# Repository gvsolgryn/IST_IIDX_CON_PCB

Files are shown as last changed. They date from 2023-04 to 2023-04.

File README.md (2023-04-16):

# IST_IIDX_CON_PCB
ist 몰에서 만든 iidx 컨트롤러 PCB 딜레이가 너무 심해서 우리 기합찬 육군(만기전역)들이 설계하기로 하였다

## 기합찬 준비운동

1. 일단 KiCAD를 받는다
2. `git` 을 다운로드 받는다
3. `git clone https://github.com/gvsolgryn/IST_IIDX_CON_PCB.git` 을 하여 우리 기합찬 PCB 프로젝트를 다운로드 받는다
4. KiCAD를 실행 시킨 뒤 프로젝트를 연다
5. 불만이 있으면 KiCAD를 이용해서 PCB 다 수정해서 머지? 요청 하면 우리 기합찬 육군들이 업데이트를 해주도록 하겠다

## 악! PCB Gerber을 이용하여 PCB를 출력하고싶어 해병님!!
1. https://jlcpcb.com/ 에 방문한다
2. gerber.zip 을 Add Gerber File 에 드래그 엔 드롭 한다
3. 결제한다!

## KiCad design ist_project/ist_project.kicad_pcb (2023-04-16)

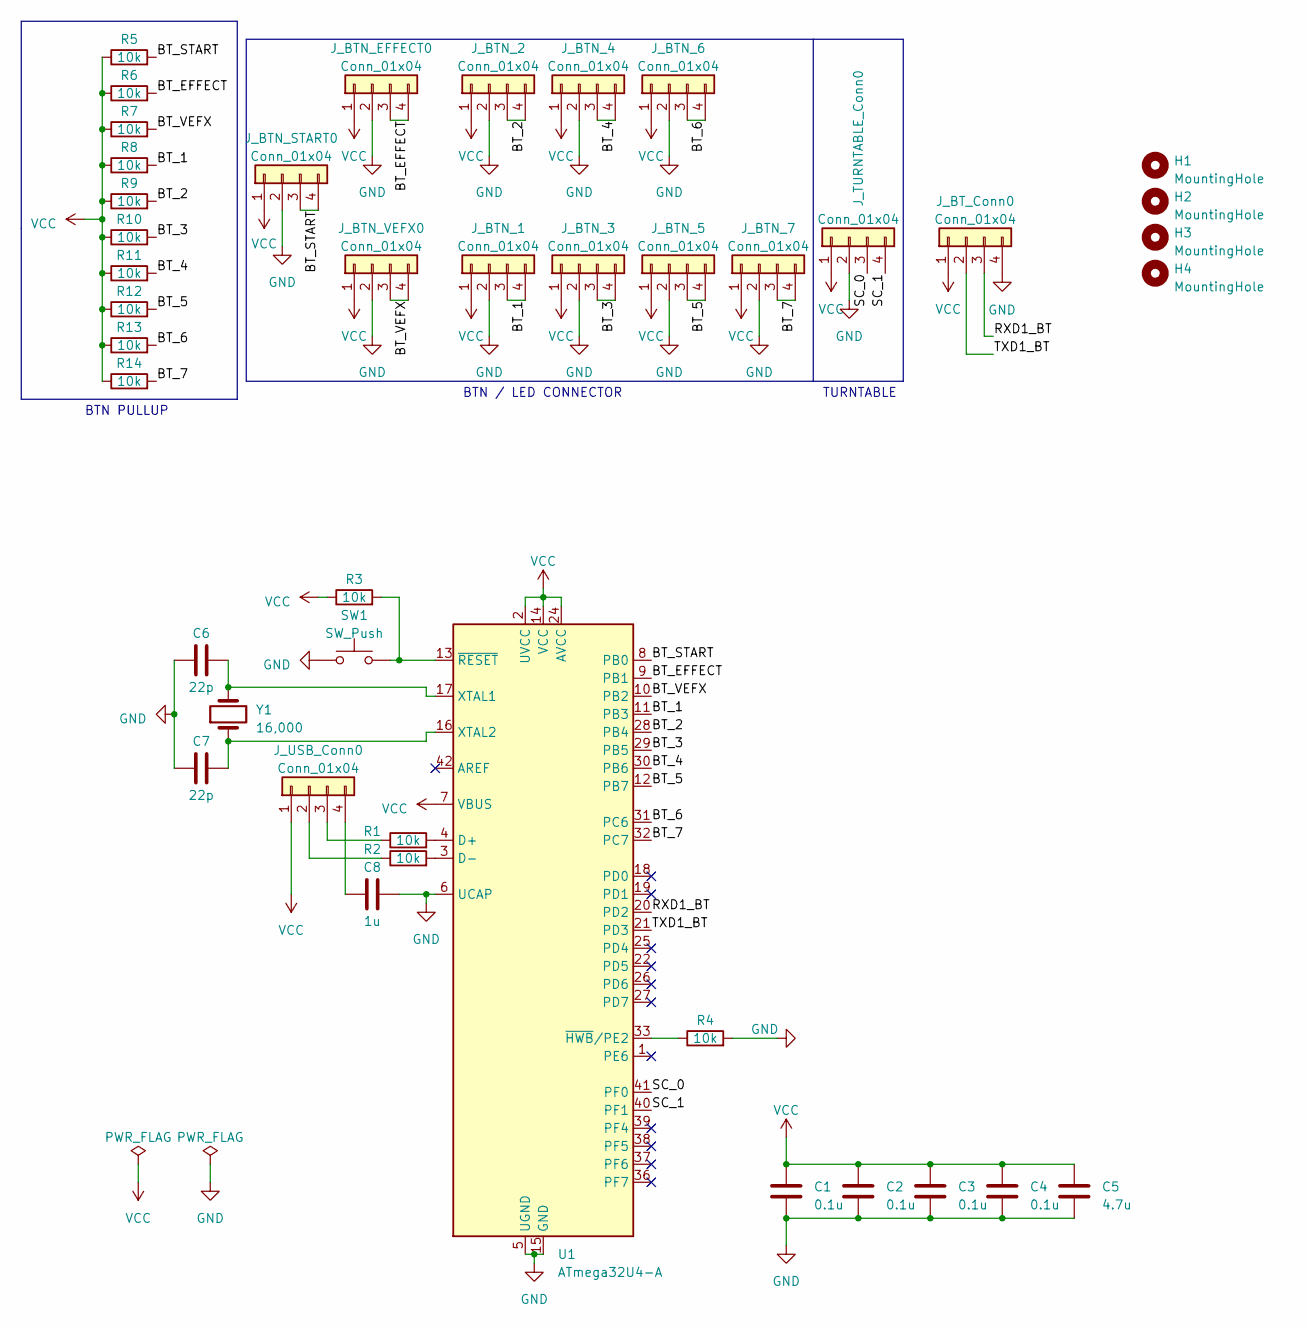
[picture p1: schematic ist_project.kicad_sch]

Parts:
C1, C2, C3, C4: 0.1u; C_0805_2012Metric_Pad1.18x1.45mm_HandSolder
C5: 4.7u; C_0805_2012Metric_Pad1.18x1.45mm_HandSolder
C6, C7: 22p; C_0805_2012Metric_Pad1.18x1.45mm_HandSolder
C8: 1u; C_0805_2012Metric_Pad1.18x1.45mm_HandSolder
H1, H2, H3, H4: MountingHole; MountingHole_3.2mm_M3_ISO7380_Pad_TopOnly
J_BTN_1, J_BTN_2, J_BTN_3, J_BTN_4, J_BTN_5, J_BTN_6, J_BTN_7: Conn_01x04; Molex_SPOX_5267-04A_1x04_P2.50mm_Vertical
J_BTN_EFFECT0: Conn_01x04; Molex_SPOX_5267-04A_1x04_P2.50mm_Vertical
J_BTN_START0: Conn_01x04; Molex_SPOX_5267-04A_1x04_P2.50mm_Vertical
J_BTN_VEFX0: Conn_01x04; Molex_SPOX_5267-04A_1x04_P2.50mm_Vertical
J_BT_Conn0: Conn_01x04; Molex_SPOX_5267-04A_1x04_P2.50mm_Vertical
J_TURNTABLE_Conn0: Conn_01x04; Molex_SPOX_5267-04A_1x04_P2.50mm_Vertical
J_USB_Conn0: Conn_01x04; Molex_SPOX_5267-04A_1x04_P2.50mm_Vertical
R1, R2, R3, R4, R5, R6, R7, R8, R9, R10, R11, R12, R13, R14: 10k; R_0805_2012Metric_Pad1.20x1.40mm_HandSolder
SW1: SW_Push; SW_Push_1P1T_NO_6x6mm_H9.5mm
U1: ATmega32U4-A; TQFP-44_10x10mm_P0.8mm
Y1: 16,000; Crystal_SMD_HC49-SD_HandSoldering

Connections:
/BT_1: J_BTN_1.3, J_BTN_1.4, R8.2, U1.11 (PB3)
/BT_2: J_BTN_2.3, J_BTN_2.4, R9.2, U1.28 (PB4)
/BT_3: J_BTN_3.3, J_BTN_3.4, R10.2, U1.29 (PB5)
/BT_4: J_BTN_4.3, J_BTN_4.4, R11.2, U1.30 (PB6)
/BT_5: J_BTN_5.3, J_BTN_5.4, R12.2, U1.12 (PB7)
/BT_6: J_BTN_6.3, J_BTN_6.4, R13.2, U1.31 (PC6)
/BT_7: J_BTN_7.3, J_BTN_7.4, R14.2, U1.32 (PC7)
/BT_EFFECT: J_BTN_EFFECT0.3, J_BTN_EFFECT0.4, R6.2, U1.9 (PB1)
/BT_START: J_BTN_START0.3, J_BTN_START0.4, R5.2, U1.8 (PB0)
/BT_VEFX: J_BTN_VEFX0.3, J_BTN_VEFX0.4, R7.2, U1.10 (PB2)
/RXD1_BT: J_BT_Conn0.3, U1.20 (PD2)
/SC_0: J_TURNTABLE_Conn0.3, U1.41 (PF0)
/SC_1: J_TURNTABLE_Conn0.4, U1.40 (PF1)
/TXD1_BT: J_BT_Conn0.2, U1.21 (PD3)
GND: C1.2, C2.2, C3.2, C4.2, C5.2, C6.1, C7.2, C8.2, J_BTN_1.2, J_BTN_2.2, J_BTN_3.2, J_BTN_4.2, J_BTN_5.2, J_BTN_6.2, J_BTN_7.2, J_BTN_EFFECT0.2, J_BTN_START0.2, J_BTN_VEFX0.2, J_BT_Conn0.4, J_TURNTABLE_Conn0.2, R4.2, SW1.1, U1.5 (UGND), U1.6 (UCAP), U1.15 (GND), U1.23 (GND), U1.35 (GND), U1.43 (GND)
unnamed: J_USB_Conn0.2, R2.1
unnamed: J_USB_Conn0.3, R1.1
unnamed: C8.1, J_USB_Conn0.4
unnamed: R1.2, U1.4 (D+)
unnamed: R2.2, U1.3 (D-)
unnamed: C6.2, U1.17 (XTAL1), Y1.2
unnamed: C7.1, U1.16 (XTAL2), Y1.1
unnamed: R4.1, U1.33 (~HWB/PE2)
unnamed: R3.2, SW1.2, U1.13 (~RESET)
VCC: C1.1, C2.1, C3.1, C4.1, C5.1, J_BTN_1.1, J_BTN_2.1, J_BTN_3.1, J_BTN_4.1, J_BTN_5.1, J_BTN_6.1, J_BTN_7.1, J_BTN_EFFECT0.1, J_BTN_START0.1, J_BTN_VEFX0.1, J_BT_Conn0.1, J_TURNTABLE_Conn0.1, J_USB_Conn0.1, R3.1, R5.1, R6.1, R7.1, R8.1, R9.1, R10.1, R11.1, R12.1, R13.1, R14.1, U1.2 (UVCC), U1.7 (VBUS), U1.14 (VCC), U1.24 (AVCC), U1.34 (VCC), U1.44 (AVCC)

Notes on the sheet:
TURNTABLE
BTN / LED CONNECTOR
BTN PULLUP

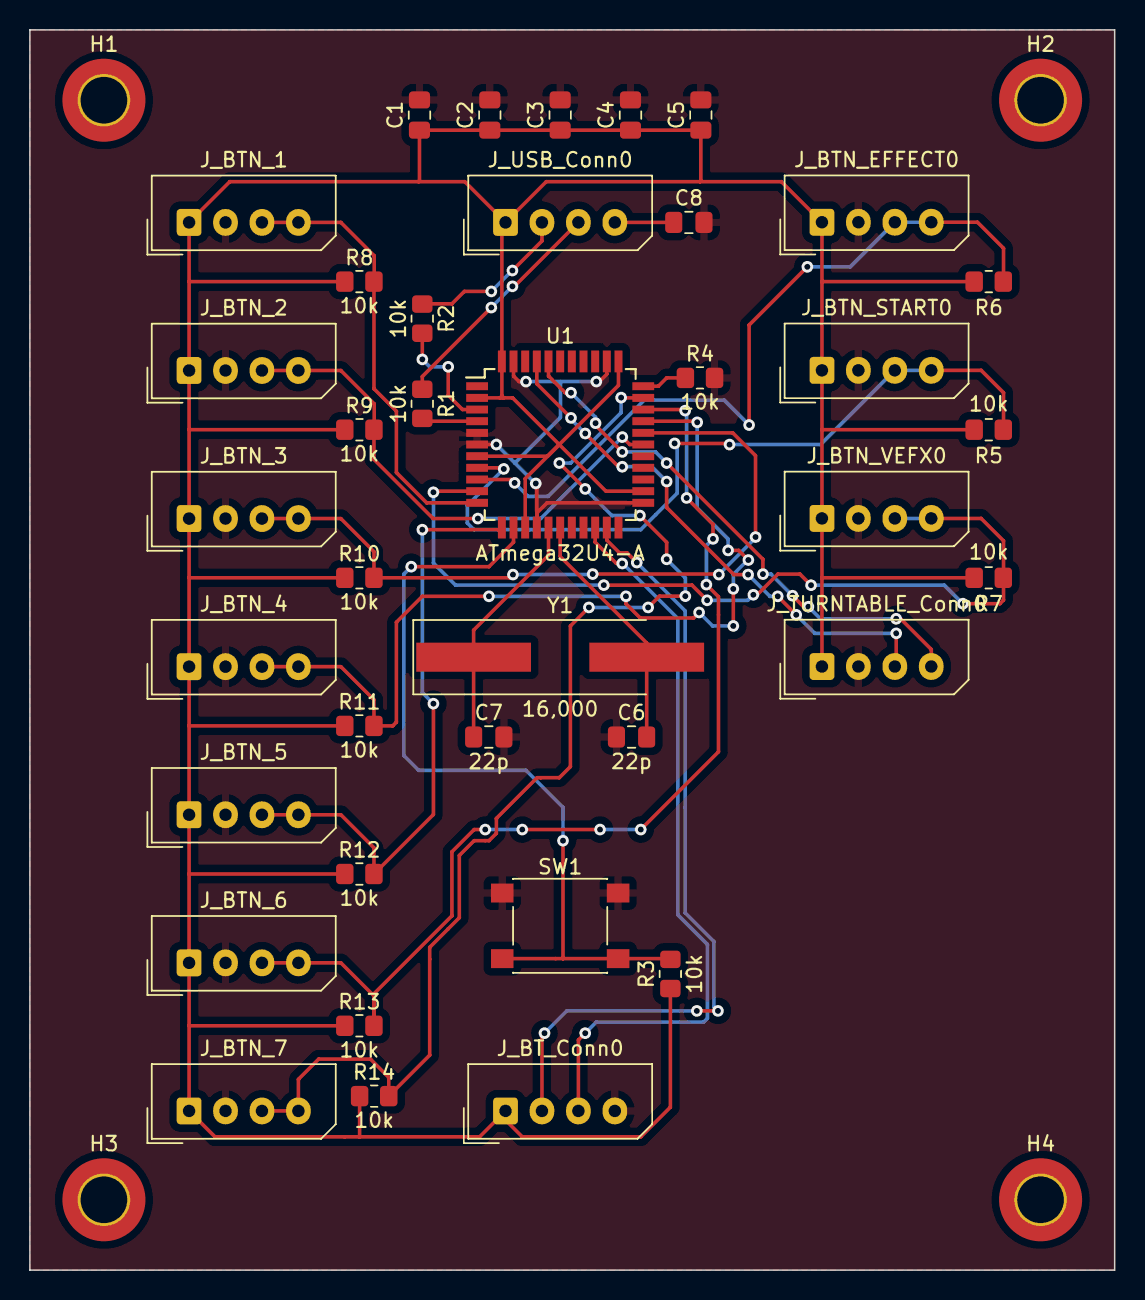
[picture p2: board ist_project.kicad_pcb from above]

Board: 2 copper layers, 74.4 x 85.1 mm, 42 parts (0 on the bottom side), 25 nets.

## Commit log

2022-10-24 Add KiCAD Project
    [ist_project.kicad_pcb, ist_project.kicad_sch]
2023-01-03 Add Pro Micro Library & footprint
    [ist_project.kicad_sch]
2023-04-13 회로도 완성 (Atmega32u4 Base)
    [ist_project.kicad_pcb, ist_project.kicad_sch]
2023-04-13 회로도 수정 / pcb 작업중
    [ist_project.kicad_pcb, ist_project.kicad_sch]
2023-04-16 PCB 그리기 완료 / Mount Hole 추가
    [ist_project.kicad_pcb, ist_project.kicad_sch]
2023-04-16 gitignore 수정
